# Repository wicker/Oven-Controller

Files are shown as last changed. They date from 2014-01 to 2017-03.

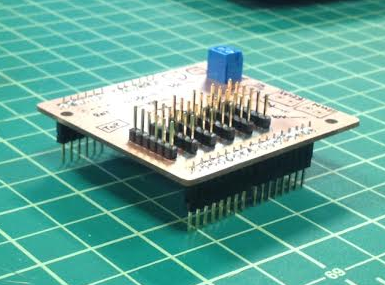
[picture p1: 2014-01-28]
pics/v1-ovenboard-side.png

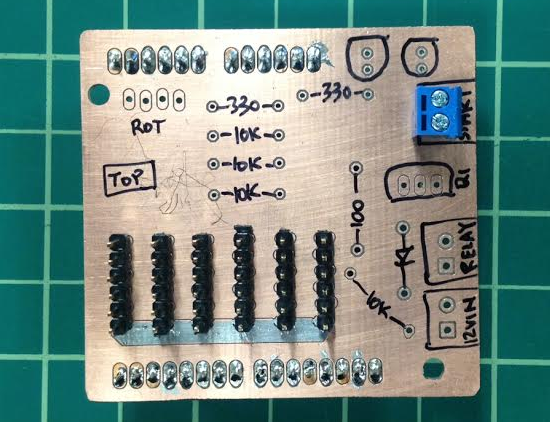
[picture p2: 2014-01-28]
pics/v1-ovenboard-top.png

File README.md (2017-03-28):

# Composites Curing Oven Controller

For the composites oven team at Portland State. 

v0 - the original schematic representation of the current working breadboard setup.  
v1 - the finished Arduino shield version on a printed circuit board. this works!  
v2 - additions to the v1 Arduino shield design.  
v3 - developing final version for OSHPark order.

**Note**  
On March 6th the oven controller is now being worked on in the mme-capstone repo in the PSAS organization: https://github.com/psas/mme-capstone

### Version 3

v3 is the final version of the oven controller installed on a 4’×8’×4’ curing oven at Portland State in the Mechanical Engineering department.

The blue case is 3D-printed and gets attached to the side of the oven. The electronics are a three-board stack with an Arduino Uno R3 on the bottom; a custom oven control board set up in the middle with screw-in Euroterminals for start switch, relay, and thermocouple wires; and a 1.8” TFT LCD Shield from Adafruit for the display on top.

The display allows the user to program up to nine steps in a temperature profile. Each step lets the user specify a ramp rate, hold temperature, and hold time. Once all the steps are set, the user should set the relay enable switch to ON and then tell the program to begin running the profile.

The program automatically detects which thermocouples are present and uses the temperature as input to a PID loop which controls ramp rate by turning on and off up to four relays which are, for our configuration, controlling two heaters, one fan, and one vent.









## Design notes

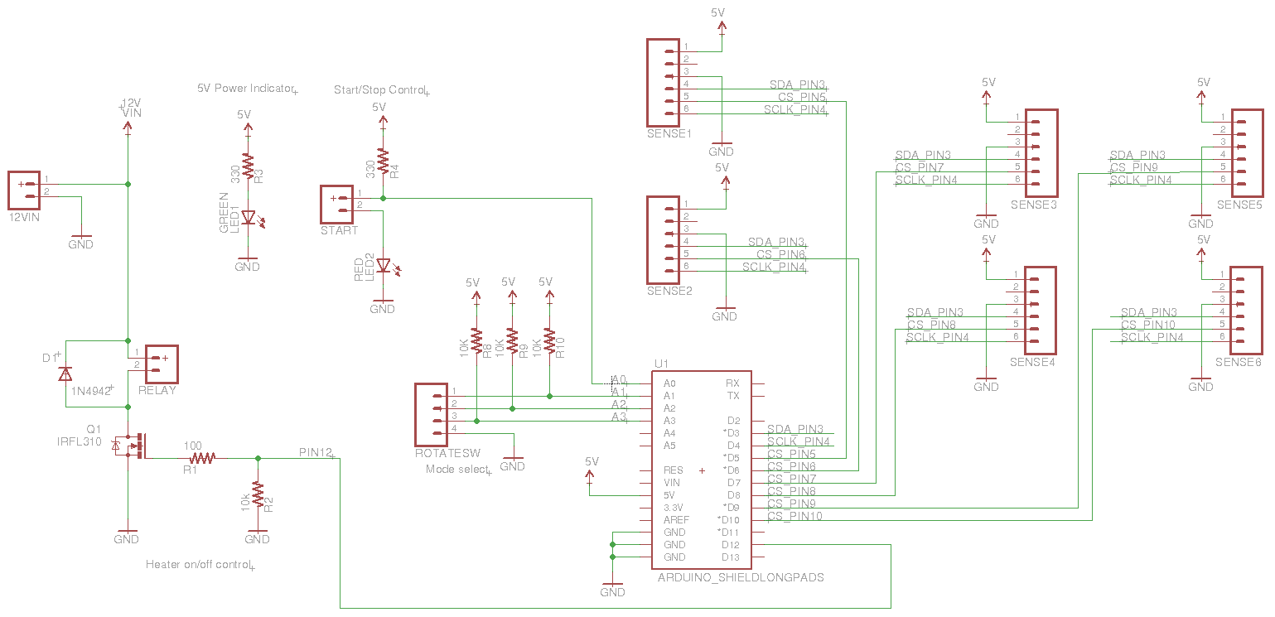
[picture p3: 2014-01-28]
pics/v1-ovenboard-schema.png

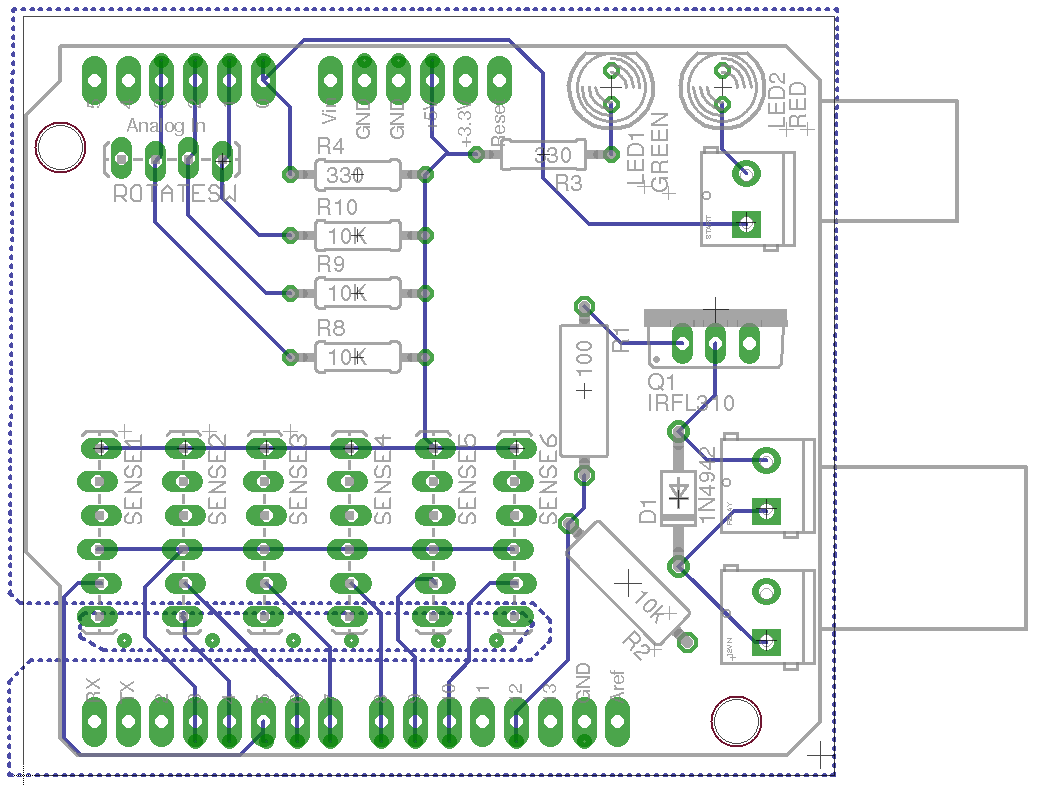
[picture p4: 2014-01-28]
pics/v1-ovenboard-layout.png

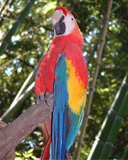
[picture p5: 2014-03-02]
src/parrot.bmp

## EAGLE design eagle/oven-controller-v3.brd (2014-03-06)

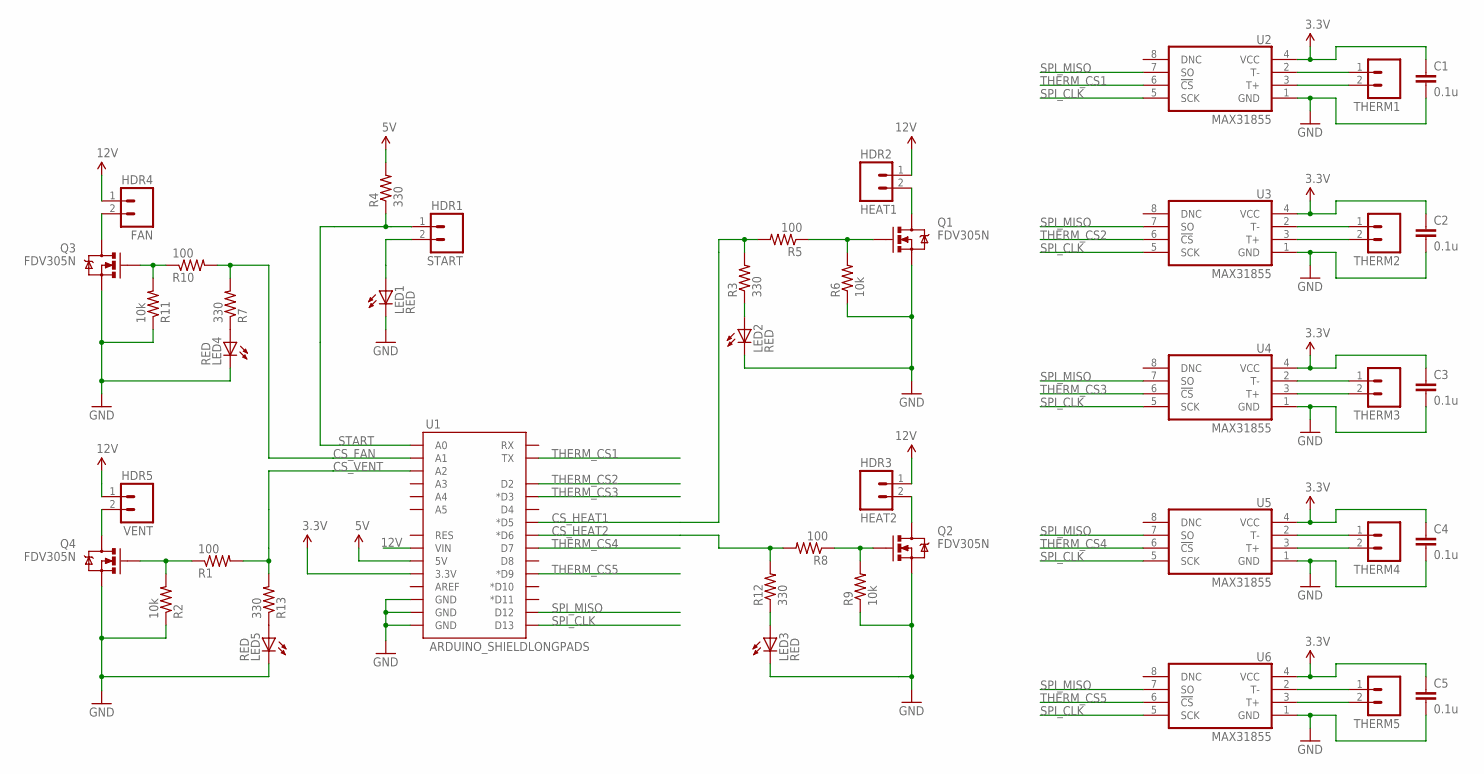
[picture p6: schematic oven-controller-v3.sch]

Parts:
C1, C2, C3, C4, C5: 0.1u; C0603K
FAN: HDR4; SCREWTERMINAL-3.5MM-2_LOCK
HEAT1: HDR2; SCREWTERMINAL-3.5MM-2_LOCK
HEAT2: HDR3; SCREWTERMINAL-3.5MM-2_LOCK
LED1, LED2, LED3, LED4, LED5: RED; LED-0603
Q1, Q2, Q3, Q4: FDV305N; SOT23-3
R1, R5, R8, R10: 100; 0603-C-NOSILK
R2, R6, R9, R11: 10k; 0603-C-NOSILK
R3, R4, R7, R12, R13: 330; 0603-C-NOSILK
START: HDR1; SCREWTERMINAL-3.5MM-2_LOCK
THERM1, THERM2, THERM3, THERM4, THERM5: M023.5MM_LOCK; SCREWTERMINAL-3.5MM-2_LOCK
U1: ARDUINO_SHIELDLONGPADS; DUEMILANOVE_SHIELD_LONGPADS
U2, U3, U4, U5, U6: MAX31855; SO-8
VENT: HDR5; SCREWTERMINAL-3.5MM-2_LOCK

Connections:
3.3V: C1.1, C2.1, C3.1, C4.1, C5.1, U1.3.3V, U2.4 (VCC), U3.4 (VCC), U4.4 (VCC), U5.4 (VCC), U6.4 (VCC)
5V: R4.2, U1.5V
12V: FAN.1, HEAT1.1, HEAT2.1, U1.VIN, VENT.1
CS_FAN: R7.2, R10.2, U1.A1
CS_HEAT1: R3.2, R5.2, U1.D5 (*D5)
CS_HEAT2: R8.2, R12.2, U1.D6 (*D6)
CS_VENT: R1.2, R13.2, U1.A2
GND: C1.2, C2.2, C3.2, C4.2, C5.2, LED1.C, LED2.C, LED3.C, LED4.C, LED5.C, Q1.2 (S), Q2.2 (S), Q3.2 (S), Q4.2 (S), R2.1, R6.1, R9.1, R11.1, U1.GND@0 (GND), U1.GND@1 (GND), U1.GND@2 (GND), U2.1 (GND), U3.1 (GND), U4.1 (GND), U5.1 (GND), U6.1 (GND)
HDR3: FAN.2, Q3.3 (D)
unnamed: Q1.1 (G), R5.1, R6.2
unnamed: Q4.1 (G), R1.1, R2.2
unnamed: Q4.3 (D), VENT.2
unnamed: HEAT1.2, Q1.3 (D)
unnamed: THERM1.1, U2.2 (T-)
unnamed: THERM1.2, U2.3 (T+)
unnamed: LED2.A, R3.1
unnamed: THERM2.1, U3.2 (T-)
unnamed: LED4.A, R7.1
unnamed: LED1.A, START.2
unnamed: THERM2.2, U3.3 (T+)
unnamed: THERM3.1, U4.2 (T-)
unnamed: THERM3.2, U4.3 (T+)
unnamed: THERM4.1, U5.2 (T-)
unnamed: THERM4.2, U5.3 (T+)
unnamed: THERM5.1, U6.2 (T-)
unnamed: THERM5.2, U6.3 (T+)
unnamed: LED3.A, R12.1
unnamed: LED5.A, R13.1
unnamed: Q2.1 (G), R8.1, R9.2
unnamed: HEAT2.2, Q2.3 (D)
unnamed: Q3.1 (G), R10.1, R11.2
SPI_CLK: U1.D13, U2.5 (SCK), U3.5 (SCK), U4.5 (SCK), U5.5 (SCK), U6.5 (SCK)
SPI_MISO: U1.D12, U2.7 (SO), U3.7 (SO), U4.7 (SO), U5.7 (SO), U6.7 (SO)
START: R4.1, START.1, U1.A0
THERM_CS1: U1.TX, U2.6 (!CS)
THERM_CS2: U1.D2, U3.6 (!CS)
THERM_CS3: U1.D3 (*D3), U4.6 (!CS)
THERM_CS4: U1.D7, U5.6 (!CS)
THERM_CS5: U1.D9 (*D9), U6.6 (!CS)

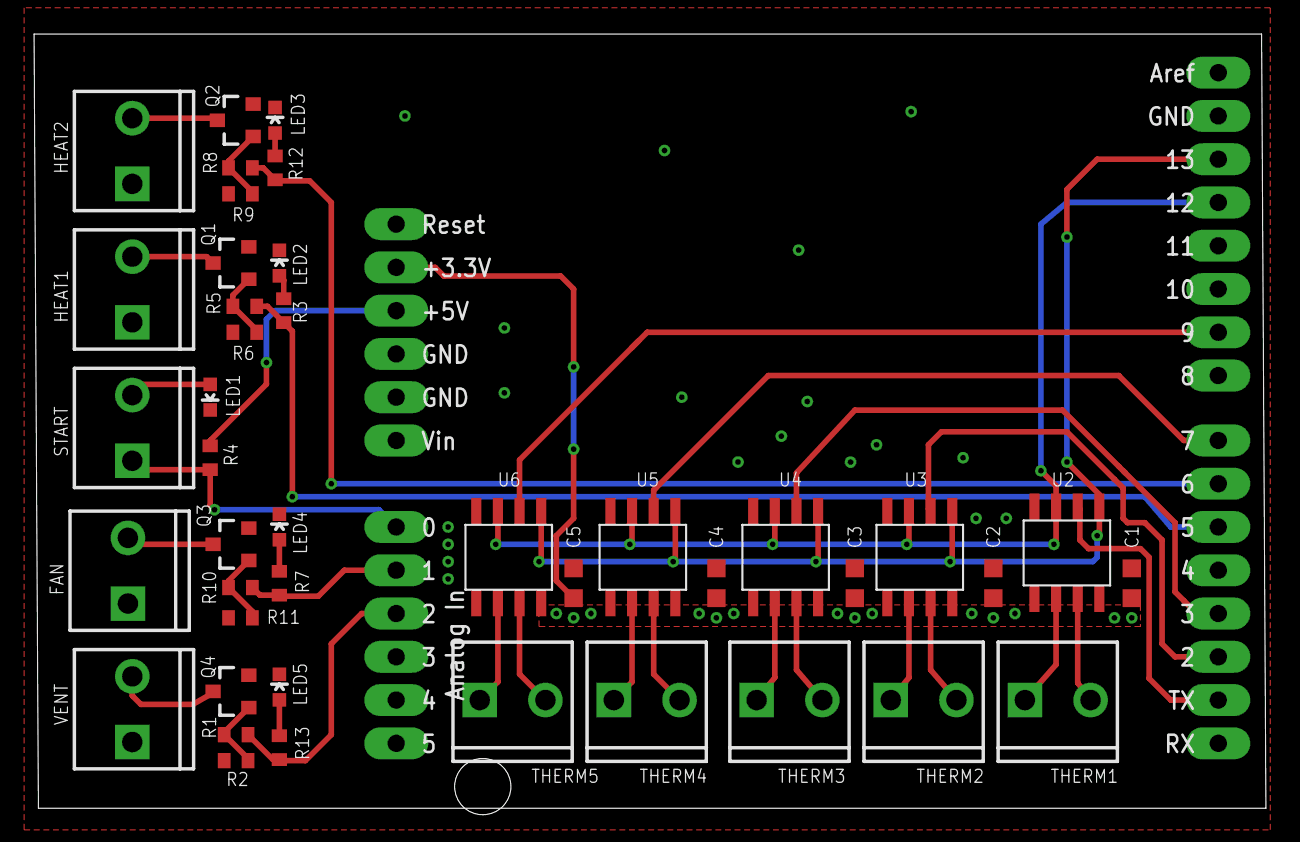
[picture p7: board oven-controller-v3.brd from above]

Board: 2 copper layers, 72.3 x 45.4 mm, 43 parts (0 on the bottom side), 39 nets.

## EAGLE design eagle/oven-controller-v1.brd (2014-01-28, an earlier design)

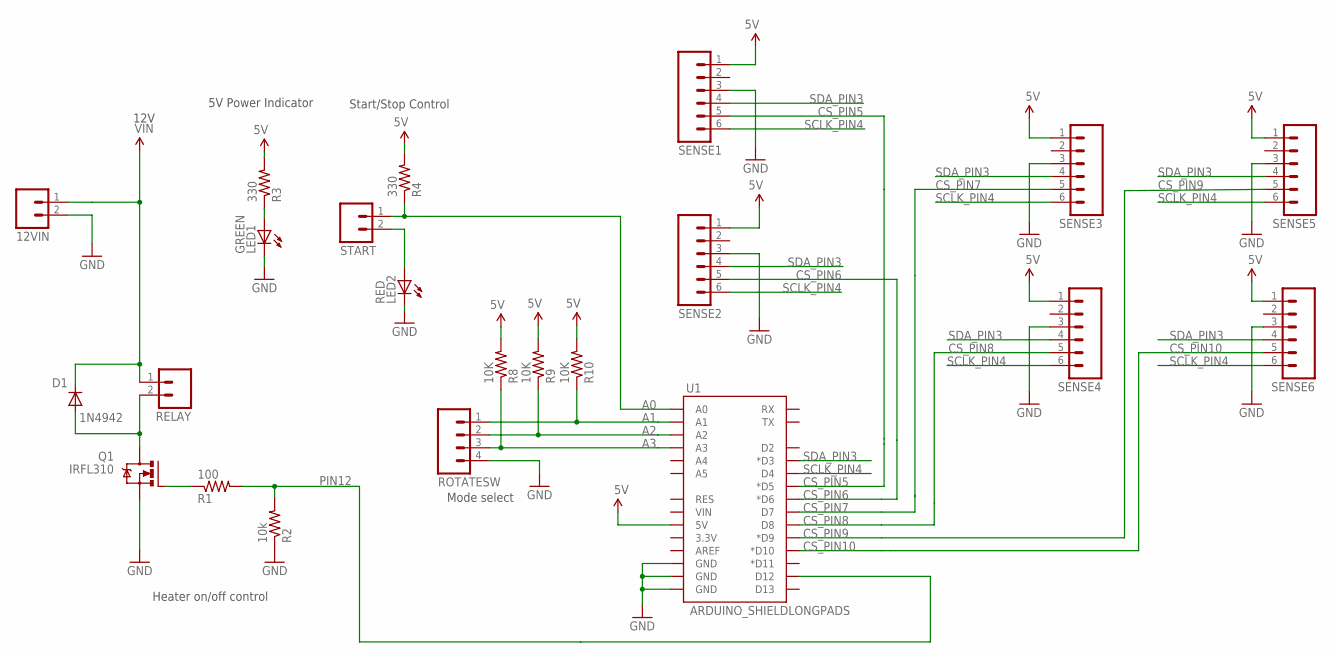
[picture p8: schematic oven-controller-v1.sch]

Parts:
12VIN: M023.5MM_LOCK; SCREWTERMINAL-3.5MM-2_LOCK
D1: 1N4942; DO41-10
LED1: GREEN; LED5MM
LED2: RED; LED5MM
Q1: IRFL310; TO220BV
R1: 100; V234/12
R2: 10k; V234/12
R3, R4: 330; 0207/10
R8, R9, R10: 10K; 0207/10
RELAY: M023.5MM_LOCK; SCREWTERMINAL-3.5MM-2_LOCK
ROTATESW: M04LOCK_LONGPADS; 1X04_LOCK_LONGPADS
SENSE1, SENSE2, SENSE3, SENSE4, SENSE5, SENSE6: M06LOCK_LONGPADS; 1X06_LOCK_LONGPADS
START: M023.5MM_LOCK; SCREWTERMINAL-3.5MM-2_LOCK
U1: ARDUINO_SHIELDLONGPADS; DUEMILANOVE_SHIELD_LONGPADS

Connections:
5V: R3.2, R4.2, R8.2, R9.2, R10.2, SENSE1.1, SENSE2.1, SENSE3.1, SENSE4.1, SENSE5.1, SENSE6.1, U1.5V
A0: R4.1, START.1, U1.A0
A1: R10.1, ROTATESW.1, U1.A1
A2: R9.1, ROTATESW.2, U1.A2
A3: R8.1, ROTATESW.3, U1.A3
CS_PIN5: SENSE1.5, U1.D5 (*D5)
CS_PIN6: SENSE2.5, U1.D6 (*D6)
CS_PIN7: SENSE3.5, U1.D7
CS_PIN8: SENSE4.5, U1.D8
CS_PIN9: SENSE5.5, U1.D9 (*D9)
CS_PIN10: SENSE6.5, U1.D10 (*D10)
GND: 12VIN.2, LED1.K (C), LED2.K (C), Q1.S, R2.1, ROTATESW.4, SENSE1.3, SENSE2.3, SENSE3.3, SENSE4.3, SENSE5.3, SENSE6.3, U1.GND@0 (GND), U1.GND@1 (GND), U1.GND@2 (GND)
unnamed: Q1.G, R1.1
unnamed: D1.A, Q1.D, RELAY.2
unnamed: LED2.A, START.2
unnamed: LED1.A, R3.1
PIN12: R1.2, R2.2, U1.D12
SCLK_PIN4: SENSE1.6, SENSE2.6, SENSE3.6, SENSE4.6, SENSE5.6, SENSE6.6, U1.D4
SDA_PIN3: SENSE1.4, SENSE2.4, SENSE3.4, SENSE4.4, SENSE5.4, SENSE6.4, U1.D3 (*D3)
VIN: 12VIN.1, D1.C, RELAY.1

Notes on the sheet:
Mode select
Heater on/off control
12V
Start/Stop Control
5V Power Indicator

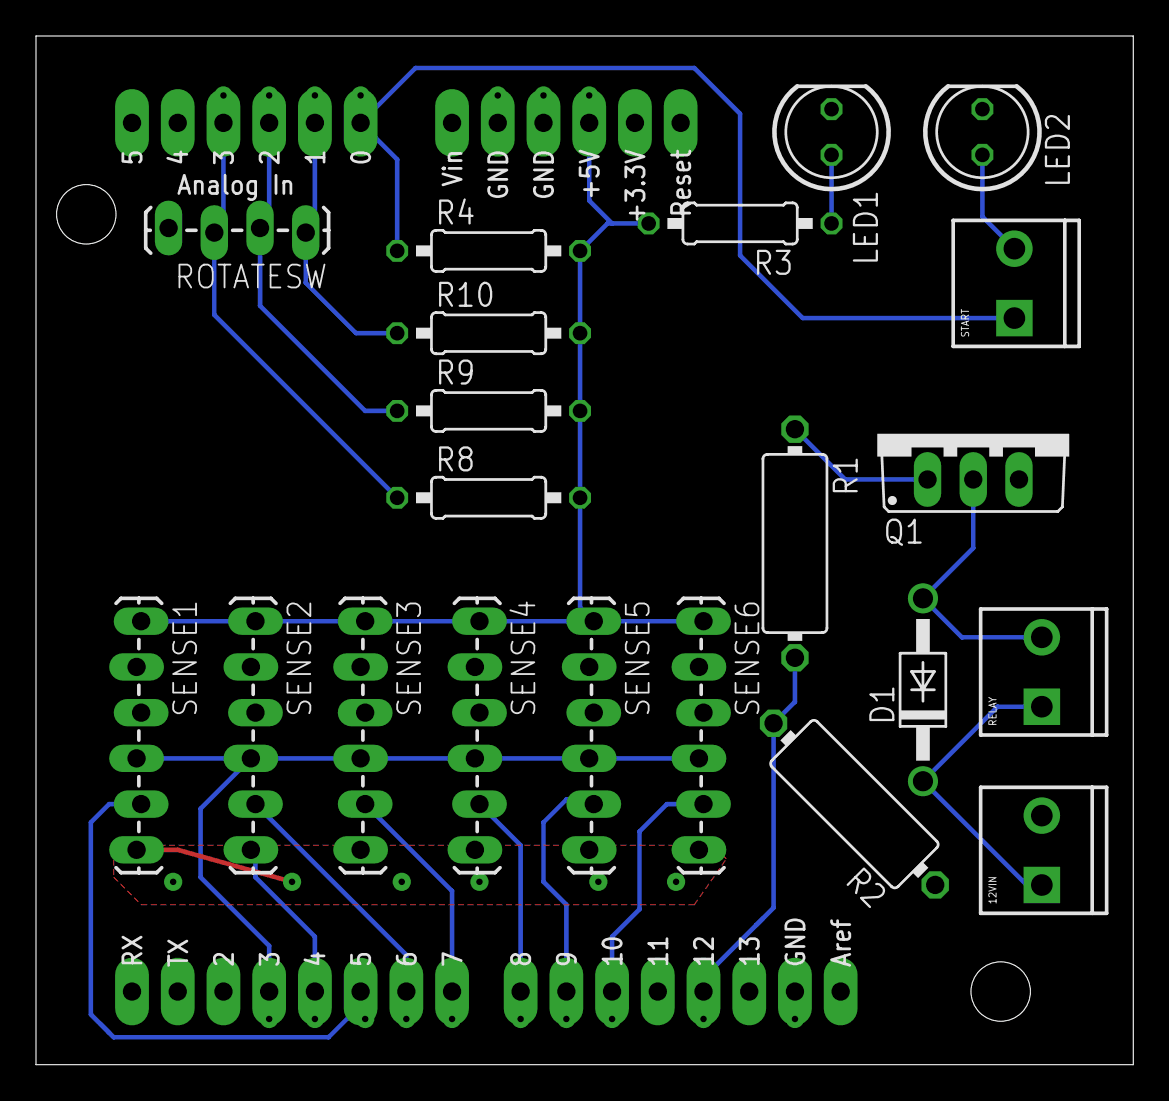
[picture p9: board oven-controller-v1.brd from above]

Board: 2 copper layers, 61.0 x 57.1 mm, 22 parts (0 on the bottom side), 20 nets.

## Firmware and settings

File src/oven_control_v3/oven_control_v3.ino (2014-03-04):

/********************************************

 This is oven control shield code v3 written by 
 Thanh Tung Nguyen and Jenner Hanni, 2014. 
 http://github.com/wicker/oven-controller/
 
 This is an oven control sketch for the Adafruit 1.8" TFT
 shield with joystick stacked on a PSAS Airframes Team 
 Oven Control Shield v3 stacked on an Arduino Uno.
 
 Our LCD shield is the BLACKTAB version.
 
 The display, SD card, and five MAX31855 thermocouple-
 to-digital chips are all on the SPI bus. The SD card 
 also uses the SD library. 
 
 We referenced code written by Limor Fried/Ladyada
 for Adafruit Industries under the MIT license.

 GENERIC TODO: Everything related to SD card.
 Otherwise look for TODO notes in comments.
 
 *******************************************/
  
#include <Adafruit_MAX31855.h>
#include <Adafruit_ST7735.h>
#include <Adafruit_GFX.h>
#include <SD.h>
#include <SPI.h>

#define OFF 0
#define ON  1

// assign state values
#define START   1
#define RUNNING 2
#define STOP    3
#define STOPPED 4

// assign joystick positions
#define BUTTON_NONE 0
#define BUTTON_DOWN 1
#define BUTTON_RIGHT 2
#define BUTTON_SELECT 3
#define BUTTON_UP 4
#define BUTTON_LEFT 5

// Pins connection
int swReset       = 0;
int thermoCS1     = 1;
int thermoCS2     = 2;
int thermoCS3     = 3;
int sdCS          = 4;
int heater1       = 5;
int heater2       = 6;
int thermoCS4     = 7;
int lcdDC         = 8;
int thermoCS5     = 9;
int lcdCS         = 10;
int spiMOSI       = 11;
int spiMISO       = 12;
int spiCLK        = 13;
int swStart       = A0;
int fan           = A1;
int vent          = A2;
int joyRead       = A3;

// initialize the LCD screen
Adafruit_ST7735 tft = Adafruit_ST7735(lcdCS, lcdDC, swReset);

// shouldn't these be #defines or at least const double, const int, etc?
double tempSet         =  350;        // farenheit
double tempInc         =  3 ;         // Temperature increament per minutes
double tempErrRange    =  0;
double tempThreshold   =  3;          // Temperature limit to turn on both heaters
int ADCThreshold       =  900;
int timeDelay          =  5000;
float timeMax          =  12780;      // (sec) timeMax=time_ramping+time_at_350; (set at 2 hours), initial temp: 70*F

// calibration 
double sensor1  =  0;
double sensor2  =  -4;
double sensor3  =  0;
double sensor4  =  0;
double sensor5  =  0;

// variables
double tempErr;
double tempSensor1;
double tempSensor2;
double tempSensor3;
double tempSensor4;
double tempSensor5;
double tempAverage;
double tempInitial;         // room temp

double currTempSet;
double tempSetLow;
double tempSetHigh;

double startTime;
double currTime;

uint8_t buttonhistory  =  0;
uint8_t joystickVal = 0;

// Thermocouples
Adafruit_MAX31855 thermocouple1(spiCLK, thermoCS1, spiMISO);
Adafruit_MAX31855 thermocouple2(spiCLK, thermoCS2, spiMISO);
Adafruit_MAX31855 thermocouple3(spiCLK, thermoCS3, spiMISO);
Adafruit_MAX31855 thermocouple4(spiCLK, thermoCS4, spiMISO);
Adafruit_MAX31855 thermocouple5(spiCLK, thermoCS5, spiMISO);

// Set the first and second heaters to ON or OFF.
void set_heaters(int val1, int val2) {
  digitalWrite(heater1, val1);  // turn off the heaters
  delay(100);
  digitalWrite(heater2, val2);  // turn off the heaters
  delay(100);
}

// Read the joystick and save the value in joystickVal.
void read_joystick() {

  float a = analogRead(3);

  a *= 5.0;
  a /= 1024.0;
  
  Serial.print("Button read analog = ");
  Serial.println(a);
  if (a < 0.2) joystickVal = BUTTON_DOWN;
  if (a < 1.0) joystickVal = BUTTON_RIGHT;
  if (a < 1.5) joystickVal = BUTTON_SELECT;
  if (a < 2.0) joystickVal = BUTTON_UP;
  if (a < 3.2) joystickVal = BUTTON_LEFT;
  else         joystickVal = BUTTON_NONE;
}

// Read the start button and update the state machine.
// Possible states are START, RUNNING, STOP, and STOPPED.
// The state is updated and the timer is incremented or
// reset to zero, depending on state.
//
// Possibly better to rename this update_state_machine().
void handle_start_button() {

  uint8_t ADCReading < ADCThreshold);

  // if the input is HIGH, handle it as a START
  if (ADCReading > ADCThreshold) {
    if (status == START) {
      status = RUNNING;
      // set start time
      startTime = millis(); 
      currTime = millis()-startTime;
      // set start temperature
      check_temp_sensors();
      tempInitial = tempAverage;
    }
    else if (status == RUNNING) {
      // check if timer has reached end of profile time
      if (currTime/1000 >= timeMax)
        status = STOP;
      else
        status = RUNNING;
      currTime = millis()-startTime;
    }
    else if (status == STOP) {
      status = STOPPED;
      currTime = 0;
    }
    else { 
      status = START;
      currTime = 0;
    }
  }

  // otherwise the input is LOW, handle it as a STOP
  else {
    if (status == START) {
      status = STOP;
      currTime = millis()-startTime;
    }
    else if (status == RUNNING) {
      status = STOP;
      currTime = millis()-startTime;
    }
    else if (status == STOP) {
      status = STOPPED;
      currTime = 0;
    }
    else { 
      status = STOPPED;
      currTime = 0;
    }
  }
}

// Poll each thermocouple value and get an average value.
// Adjusting by 32 for each tempSensor value
// eliminates the SPI disconnection.
void check_temp_sensors() {
  float tempSum=0;
  int count=0;
  tempSensor1 = thermocouple1.readFarenheit()+sensor1;
  if (tempSensor1>32) {
    count=count+1;
    tempSum=tempSum+tempSensor1;
  }
  delay(10);
  tempSensor2 = thermocouple2.readFarenheit()+sensor2;
  if (tempSensor2>32) {
    count=count+1;
    tempSum=tempSum+tempSensor2;
  }
  delay(10);
  tempSensor3 = thermocouple3.readFarenheit()+sensor3;
  if (tempSensor3>32) {
    count=count+1;
    tempSum=tempSum+tempSensor3;
  }
  delay(10);
  tempSensor4 = thermocouple4.readFarenheit()+sensor4;
  if (tempSensor4>32) {
    count=count+1;
    tempSum=tempSum+tempSensor4;
  }
  delay(10);
  tempSensor5 = thermocouple5.readFarenheit()+sensor5;
  if (tempSensor5>32) {
    count=count+1;
    tempSum=tempSum+tempSensor5;
  }
  delay(10);
  tempAverage = tempSum/count;
}

// TODO: FIGURE THIS OUT AND EXPLAIN IT BETTER
// Not sure exactly what this is doing.
// It's deciding how to update the heaters, anyway.
// This really ought to take the state use it.
void update_heaters(int state) {
  currTempSet=min(350, currTime/1000/60*tempInc+tempInitial);
  tempSetLow= currTempSet-tempErrRange;
  tempSetHigh= currTempSet+tempErrRange;  

  if (tempAverage < tempSetLow && tempAverage > 32) {
    if (tempAverage < tempSetLow - tempThreshold) 
      set_heaters(ON,ON);
    else 
      set_heaters(ON,OFF);
  }
  else {
    if (tempAverage > tempSetHigh + tempThreshold)
      set_heaters(OFF,OFF);
    else 
      set_heaters(OFF,ON);
  }
}

// Display information
// TODO: EVERYTHING
void update_display() {
  Serial.print("Current temperature F = ");
  Serial.print(tempSensor1);
  Serial.print(" ");
  Serial.print(tempSensor2);
  Serial.print(" ");
  Serial.print(tempSensor3);
  Serial.print(" ");
  Serial.print(tempSensor4);
  Serial.print(" ");
  Serial.print(tempSensor5); 
  Serial.print("Average temperature F = ");
  Serial.println(tempAverage);

  uint8_t b = readButton();
  tft.setTextSize(3);
  if (b == BUTTON_DOWN) {
    tft.setTextColor(ST7735_RED);
    tft.setCursor(0, 10);
    tft.print("Down ");
    buttonhistory |= 1;
  }
  if (b == BUTTON_LEFT) {
    tft.setTextColor(ST7735_YELLOW);
    tft.setCursor(0, 35);
     tft.print("Left ");
    buttonhistory |= 2;
  }
  if (b == BUTTON_UP) {
    tft.setTextColor(ST7735_GREEN);
    tft.setCursor(0, 60);
    tft.print("Up"); 
    buttonhistory |= 4;
  }
  if (b == BUTTON_RIGHT) {
    tft.setTextColor(ST7735_BLUE);
    tft.setCursor(0, 85);
    tft.print("Right");
    buttonhistory |= 8;
  }
  if ((b == BUTTON_SELECT) && (buttonhistory == 0xF)) {
    tft.setTextColor(ST7735_MAGENTA);
    tft.setCursor(0, 110);
    tft.print("SELECT");
    buttonhistory |= 8;
    delay(2000);
    Serial.print("Initializing SD card...");
    if (!SD.begin(sdCS)) {
      Serial.println("failed!");
      return;
    }
  }
}

// Set up all the pins and serial connection
void setup() {
  Serial.begin(9600);
  
  // set up the pins
  pinMode(heater1, OUTPUT);
  pinMode(heater2, OUTPUT);
  pinMode(fan, OUTPUT);
  pinMode(vent, OUTPUT);
  
  // wait for MAX chips to stabilize
  delay(1000);
  set_heaters(OFF,OFF);

  // get the initial oven temperature
  check_temp_sensors();
  tempInitial = tempAverage;
 
  // init the LCD and fill screen
  tft.initR(INITR_BLACKTAB);
  tft.fillScreen(0x0000);

  // init the LCD with user selection
  // TODO: ADD A GET_PROFILE OR SOMETHING TO GET INFO FROM USER
  // AND WORK THAT INTO THE STATE MACHINE LOGIC
}

// TODO: VERIFY THIS LOGIC
// TODO: FIGURE OUT WHERE DELAYS ARE NECESSARY AND ADD THEM
void loop() {

  // get inputs
  read_joystick();
  check_temp_sensors();

  // update state machine based on those inputs
  handle_start_button();
  update_heaters(status);

  // update display
  update_display();

  delay(100);

} 

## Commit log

2014-01-24 First commit.
    [oven-controller-v0.sch, oven-controller-v1.brd, oven-controller-v1.sch]
2014-01-24 All parts on the board, cleaned up layout.
    [oven-controller-v1.brd, oven-controller-v1.sch]
2014-01-25 Schematic and layout done. Connections to Arduino will have to be female headers because we don't have plated vias.
    [oven-controller-v1.brd, oven-controller-v1.sch]
2014-01-25 Dimensions and spacing fixes.
    [oven-controller-v1.brd]
2014-01-27 Fixed for LPKF limitations. Ready for Nystrom via method.
    [oven-controller-v1.xln]
2014-01-27 Final board routed.
    [oven-controller-v1.brd]
2014-01-28 Moved it around for better screenshot.
    [oven-controller-v1.sch]
2014-01-28 Removed unnecessary layers.
    [oven-controller-v1.brd, oven-controller-v1.sch]
2014-01-30 Tung added a fan controlling FET with LED and changed 12V to come through Arduino. We're pretty sure it'll work.
    [oven-controller-v2.sch]
2014-01-30 Started board layout. Made resistors Sparkfun axial footprint.
    [oven-controller-v2.brd, oven-controller-v2.sch]
2014-02-01 Laid out board for v2. ERC and DRC good. Generated Gerbers.
    [oven-controller-v2.brd, oven-controller-v2.sch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]
2014-02-01 Uh, definitely update vias before making board.
    [oven-controller-v2.brd]
2014-03-01 Switching to SMT parts. Schematic rough draft. Still needs FETs. Board rough done.
    [oven-controller-v3.brd, oven-controller-v3.sch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]
2014-03-02 Removed diodes. FETs now SOT23-3. Schematic and layout done. Ready for review.
    [oven-controller-v3.brd, oven-controller-v3.sch]
2014-03-02 Moved the INO to its own folder so Arduino IDE can read it.
2014-03-02 Updated sketch to reflect new pinouts. It compiles and runs. Not tested with oven board attached, only LCD.
2014-03-04 Changed sensors_reading() function to check_temp_sensors() and narrowed focus.
2014-03-04 Wrote handle_joystick() and handle_start_button() as separate functions where start button updates state.
2014-03-04 Merged all four heater functions into one that takes two inputs.
2014-03-04 Added timer reaching maximum to state machine handling function.
2014-03-06 Changing directory structure.
    [oven-controller-v0.sch, oven-controller-v1.brd, oven-controller-v1.sch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]
2014-03-06 Changed FET resistors. Fixed routing. Passed ERC and DRC. Ready for review.
    [oven-controller-v3.brd, oven-controller-v3.sch]

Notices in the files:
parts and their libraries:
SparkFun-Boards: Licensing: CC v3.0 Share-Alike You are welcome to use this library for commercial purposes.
